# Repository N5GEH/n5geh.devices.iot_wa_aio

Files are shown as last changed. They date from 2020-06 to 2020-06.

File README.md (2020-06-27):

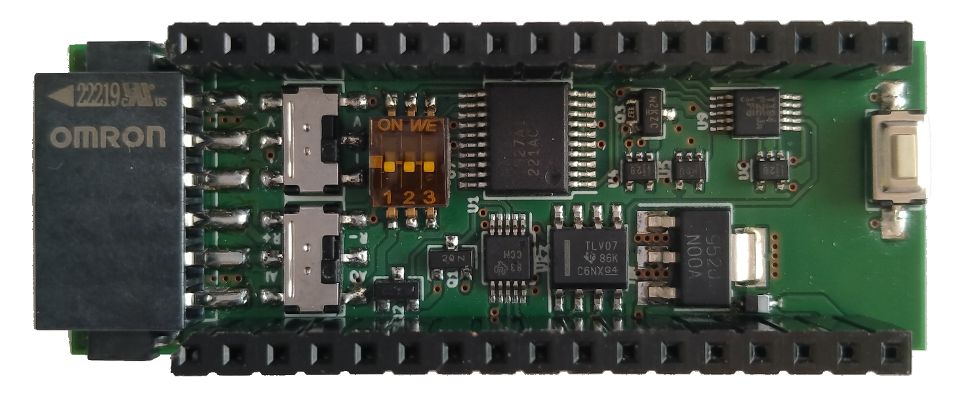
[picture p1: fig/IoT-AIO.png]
#   IoT-AIO <br/> Analog IO IoT Wireless Adapter

IoT-AIO is a wireless adapter for developing IoT applications for Industrial and Building Automation Systems based on the Espressif chipset ESP32. The adapter is compatible with:
- current loop signals (0/4-20 mA)
- voltage signals (0/2-10 V)
- passive sensors (RTD, Strain Gauge,..)

The library allows the implemention of IoT applications that rely on MQTT protocol via WiFi/NB-IoT/LTE Cat-M1 interfaces.

## Adapter versions
The Iot-AIO wireless adapter is available in two versions developed using [KiCAD 5.1](https://kicad-pcb.org/) and compatible with:
- [ESP32-PICO-KIT v4](https://docs.espressif.com/projects/esp-idf/en/latest/esp32/hw-reference/esp32/get-started-pico-kit.html) - is an ESP32-based mini development board produced by [Espressif](https://espressif.com/). The board features integrated Wifi and BLE capabilites.
- [FiPy](https://pycom.io/product/fipy/) - is an ESP32-based mini development board produced by [Pycom](https://pycom.io/). The board features integrated Wifi, BLE, LoRa, Sigfox, NB-IoT and LTE Cat-M1

## Development Framework
IoT-AIO relies on the Espressif IoT Development Framework [ESP-IDF](https://github.com/espressif/esp-idf), the official development framework for the [ESP32](https://espressif.com/en/products/hardware/esp32/overview) chip.

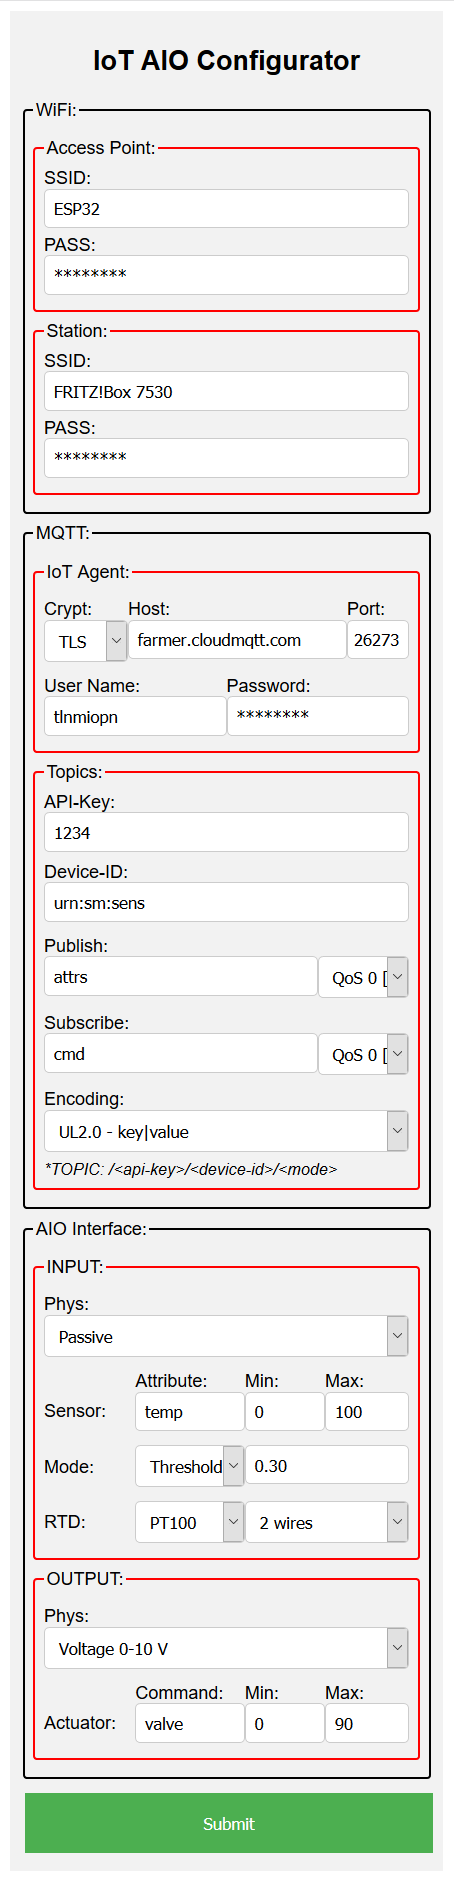
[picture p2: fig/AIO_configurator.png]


The adapter can be easily configured at run-time via a web interface based on HTML forms. The software configurator can be accessed by connecting to the adapter while in AP mode and typing in the browser the IP address `192.168.1.4`. After a succesful change in configuration the wireless adapter will reset. Source code and additional documentation can be found here:
- [AIO Configurator](Firmware/doc/aio_configurator.md)
- [HTML Request Page](Firmware/doc/aio_configurator_request.html)
- [HTML Response Page](Firmware/doc/aio_configurator_response.html)
- [Further Developments](Firmware/doc/developments.md)

## Configuration
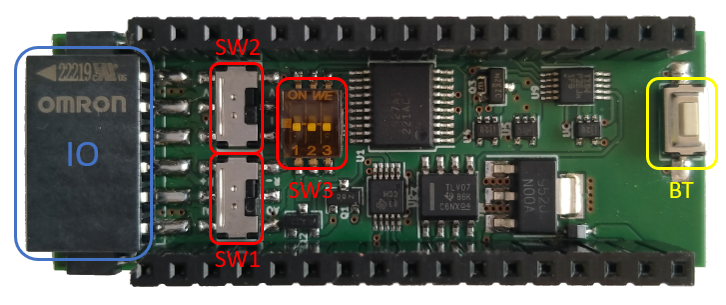
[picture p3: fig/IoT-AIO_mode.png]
IoT-AIO Mode


### Pinout
IO pinout (top-down):
- 0: GND
- 1: I- amperometric negative pin
- 2: I+ amperometric positive pin
- 3: AO/V- analog output/voltmetric negative pin
- 4: AI/V+ analog output/voltmetric positive pin
- 5: 12 V power supply (use input resistor 120 Ω / 1.5 W for 24 V input)

### Mode
The working mode of the adapter is selected using SW1
- UP: passive mode
    - pin 3 -> V-
    - pin 4 -> V+
- DOWN: analog IO mode
    - pin 3 -> AO
    - pin 4 -> AI

### Input mode
When SW1(DOWN) the input mode of the adapter is selected using SW2
- UP: voltage input mode allows for signals in the range 0 to 10 V
- DOWN: current input mode  allows for signals in the range 0 to 20 mA

### Output mode
When SW1(DOWN) the output mode of the adapter is selected using SW3(1):
- UP: voltage output mode allows for signals in the range 0 to 10 V
- DOWN: current output mode  allows for signals in the range 0 to 20 mA

### Passive mode
When SW1(UP) the output mode of the adapter is selected using SW3(2,3)

| Mode | SW3(2) | SW3(3) |
|:---:|:---:|:---:|
| 2-wires | UP | UP |
| 3-wires | UP |  DOWN  |
| 4-wires |  DOWN  |  DOWN  |

### Functions button
The push button BT performs multiple operations depending on the pressure time Tp.

| Pressure Time | Action |
|:---:|:---|
| Tp < 1s | Performs a soft-reset of the adapter |
|1s < Tp < 5s | Enables the AP mode. If not previously changed, the device will be visible by default with the SSID `ESP_<MAC>`, where <MAC> is the MAC address of the adapter network interface in hex format|
|5s < Tp | Performs a hard-reset of the adapter deleting the previously stored configuration|

# Publications

We kindly ask academic publications employing based or inspired to IoT-AIO to cite at least one of the following papers:

- M.H. Schraven, C. Guarnieri Calò Carducci, M.A. Baranski, D. Mueller, A. Monti, “Designing a Development Board for Research on IoT Appli-cations in Building Automation Systems,” 36th International Symposiumon  Automation  and  Robotics  in  Construction  (ISARC  2019),  Banff,Canada, 2019, pp. 82-90, [DOI: 10.22260/ISARC2019/0012](https://doi.org/10.22260/ISARC2019/0012)
- C. Guarnieri Calò Carducci, A. Monti, M. H. Schraven, M. Schumacher and D. Mueller, “Enabling ESP32-based IoT Applications in Building Automation Systems,” 2019 II Workshop on Metrology for Industry 4.0 and IoT (MetroInd4.0&IoT), Naples, Italy, 2019, pp. 306-311, [DOI: 10.1109/METROI4.2019.8792852](https://doi.org/10.1109/METROI4.2019.8792852)

# Copyright

2019-2020, Institute for Automation of Complex Power Systems, EONERC  

# License

<br />This work is licensed under a <a rel="license" href="http://creativecommons.org/licenses/by/4.0/">Creative Commons Attribution 4.0 International License</a>.

# Contact
EONERC ACS Logo (http://www.acs.eonerc.rwth-aachen.de)

- [Carlo Guarnieri Calò Carducci (PhD)](mailto:cguarnieri@eonerc.rwth-aachen.de)

[Institute for Automation of Complex Power Systems (ACS)](http://www.acs.eonerc.rwth-aachen.de)  
[EON Energy Research Center (EONERC)](http://www.eonerc.rwth-aachen.de)  
[RWTH University Aachen, Germany](http://www.rwth-aachen.de)

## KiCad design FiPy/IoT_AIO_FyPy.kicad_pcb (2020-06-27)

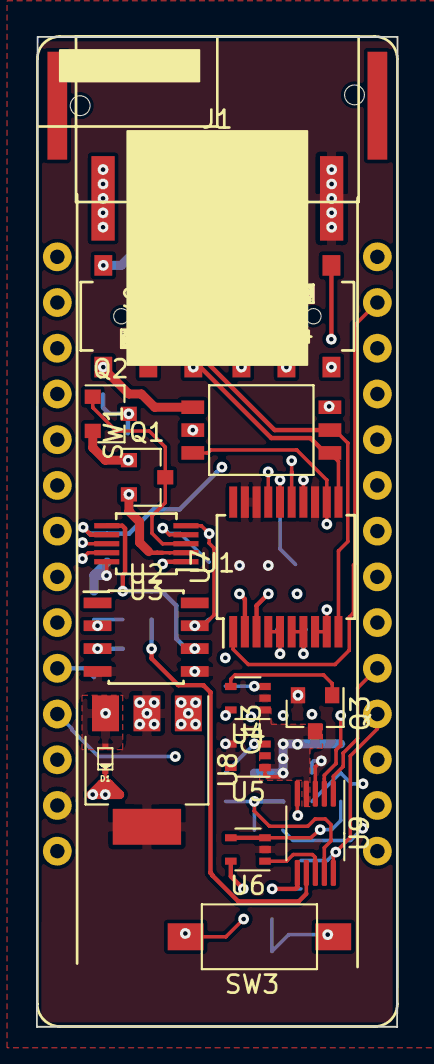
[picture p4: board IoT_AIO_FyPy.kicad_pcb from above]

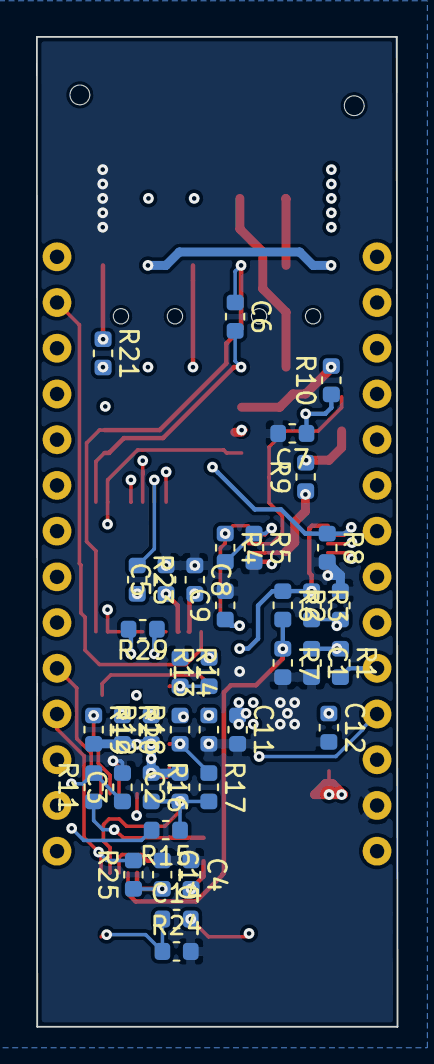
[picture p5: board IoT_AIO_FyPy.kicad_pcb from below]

Board: 4 copper layers, 20.0 x 55.0 mm, 57 parts (39 on the bottom side), 52 nets.

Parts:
C1, C3, C6: 1u; C_0603_1608Metric
C2, C4, C5, C8, C9, C10, C12, C13: 100n; C_0603_1608Metric
C7: 10n; C_0603_1608Metric
C11: 220n; C_0603_1608Metric
C14: 100n; R_0603_1608Metric
D1: D_Schottky; BAS52
J1: Conn_01x06; XW4L-06A1-H1
Q1: MMBT5087LT3G; SOT-23
Q2: ISS55EP06LMXTSA1; SOT-23
Q3: SI2302; SOT-23
R1, R11, R24, R25: 10k; R_0603_1608Metric
R2: 4.7k 0.1%; R_0603_1608Metric
R3: 10k 0.1%; R_0603_1608Metric
R4: 22k; R_0603_1608Metric
R5: 8.2k; R_0603_1608Metric
R6, R21: 33k 0.1%; R_0603_1608Metric
R7, R19: 3.3k 0.1%; R_0603_1608Metric
R8: 4990 0.1%; R_0603_1608Metric
R9, R10: 15; R_0603_1608Metric
R12, R14: 3.3k; R_0603_1608Metric
R13: 33k; R_0603_1608Metric
R15: 600 0.1%; R_0603_1608Metric
R16: 1k 0.1%; R_0603_1608Metric
R17: 2.2k 0.1%; R_0603_1608Metric
R18: 500; R_0603_1608Metric
R20: 45.3 0.1%; R_0603_1608Metric
R23: 4.7k; R_0603_1608Metric
R29: 400 0.1%; R_0603_1608Metric
SW1: SW_3PST; 416131160803
SW2: SW_SPDT_x2; AYZ0202AGRL
SW3: SW_Push; PTS636
SW4: SW_DPDT_x2; AYZ0202AGRL
U1: FiPy
U2: TLV07IDR; SOIC-8_3.9x4.9mm_P1.27mm
U3: XTR111AIDGQR; MSOP-10_3x3mm_P0.5mm
U4, U6: TLV333IDCKR; SOT-353_SC-70-5
U5: LM4040DCK-2.0; SOT-353_SC-70-5
U7: MAX31865; SSOP-20_5.3x7.2mm_P0.65mm
U8: LM340MP-5.0/NOPB; SOT-223-3_TabPin2
U9: TMUX1204; VSSOP-10_3x3mm_P0.5mm

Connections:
+3V3: C4.2, C5.1, C8.2, C10.2, C13.2, R12.2, R18.2, R23.2, R25.1, U1.26, U4.5, U6.5, U7.2, U7.3, U9.5, U9.6
+5V: D1.1, U1.28
+24V: C11.1, J1.6, U3.1, U8.1
/ADC_AI: C3.1, R11.2, U1.15
/AI: SW2.1, SW4.5
/AI/AOCAL: R6.2, R7.1, U9.7
/AI/Vcal: C2.1, R15.1, R16.2, R17.2, U9.9
/AO: R10.2, SW1.1, SW2.4
/AO/VREGF: C9.1, R4.1, U2.7, U3.5
/CAL_GPIO: R15.2, U1.10
/CS_SENSOR: R23.1, U1.6, U7.16
/DRDY_SENSOR: U1.13, U7.1
/IFORCE+: J1.3, SW1.3, U7.8, U7.9
/IFORCE-: J1.2, SW1.5, U7.12
/MISO_SENSOR: U1.11, U7.17
/MOSI_SENSOR: U1.12, U7.14
/MUX_A0: U1.5, U9.1
/MUX_A1: R25.2, U1.4, U9.10
/OFFSET_DAC: R13.2, U1.23
/RTDIN+: C6.1, SW1.4, SW2.3, U7.10
/RTDIN-: C6.2, SW1.6, SW2.6, U7.11
/SCK_SENSOR: U1.25, U7.15
/XTR111_EF: U1.18, U3.8
/XTR111_OD: U1.17, U3.9
/XTR111_PWM: R1.2, U1.24
GND: C1.2, C3.2, C4.1, C5.2, C7.2, C8.1, C9.2, C10.1, C11.2, C12.2, C13.1, J1.1, Q3.2, R2.2, R5.2, R7.2, R8.2, R14.1, R24.2, U1.27, U2.4, U3.10, U4.2, U6.2, U7.13, U7.18, U7.19, U8.2, U9.3
GNDA: C2.2, Q3.3, R12.1, R16.1, R19.2, R20.2, U4.1, U5.1, U9.4
unnamed: C1.1, R1.1, U2.3
unnamed: C7.1, Q2.3, R10.1
unnamed: C12.1, D1.2, U8.3
unnamed: C14.1, R24.1, SW3.1
unnamed: C14.2, SW3.2, U1.16
unnamed: J1.4, SW2.5
unnamed: J1.5, SW2.2
unnamed: Q1.1, Q2.2, R9.2
unnamed: Q1.2, R9.1, U3.2
unnamed: Q1.3, Q2.1, U3.3
unnamed: Q3.1, U4.4
unnamed: R2.1, R3.2, U2.2
unnamed: R3.1, R6.1, U2.6, U3.6
unnamed: R4.2, R5.1, U3.4
unnamed: R8.1, SW1.2, U3.7
unnamed: R11.1, U6.3, U6.4
unnamed: R13.1, R14.2, U4.3
unnamed: R17.1, R18.1, U5.3
unnamed: R19.1, SW4.2, U9.2
unnamed: R20.1, SW4.3, SW4.6
unnamed: R21.1, SW4.4
unnamed: R21.2, SW4.1
unnamed: R29.1, U7.4, U7.5
unnamed: R29.2, U7.6, U7.7
unnamed: U6.1, U9.8

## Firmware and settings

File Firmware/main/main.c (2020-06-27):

#include <stdio.h>
#include "esp_log.h"
#include "esp_system.h"

#include "AIO_Conf.h"
#include "AIO_Board.h"
#include "AIO_Netw.h"
#include "AIO_Mqtt.h"
#include "AIO_Intr.h"
#include "MAX31865.h"

static aio_conf_t aio_conf;
static const char *TAG = "APP";


void app_main(void)
{

	ESP_LOGI(TAG, "Startup..");
	ESP_LOGI(TAG, "Free memory: %d bytes", esp_get_free_heap_size());
	ESP_LOGI(TAG, "IDF version: %s", esp_get_idf_version());

	ESP_LOGI(TAG, "Configuring Log levels");
	esp_log_level_set("*", ESP_LOG_INFO);
	esp_log_level_set("MQTT_CLIENT", ESP_LOG_VERBOSE);
	esp_log_level_set("TRANSPORT_TCP", ESP_LOG_VERBOSE);
	esp_log_level_set("TRANSPORT_SSL", ESP_LOG_VERBOSE);
	esp_log_level_set("TRANSPORT", ESP_LOG_VERBOSE);
	esp_log_level_set("OUTBOX", ESP_LOG_VERBOSE);
	
	esp_log_level_set("MAX31865", ESP_LOG_WARN);
	esp_log_level_set("AIO_Board", ESP_LOG_INFO);
	esp_log_level_set("AIO_Conf", ESP_LOG_INFO);
	esp_log_level_set("AIO_Netw", ESP_LOG_INFO);
	esp_log_level_set("AIO_Mqtt", ESP_LOG_INFO);
	esp_log_level_set("AIO_Intr", ESP_LOG_INFO);


	ESP_LOGI(TAG, "Init modules..");
	init_CONF(&aio_conf, AIO_CONF_INIT_MEMORY);						// Init AIO Configuration
	init_AIO (&aio_conf);											// Init AIO Board
	init_NETW(&aio_conf);											// Init Network
	init_MQTT(&aio_conf);											// Init MQTT
	init_INTR();													// Init Interrupts

    while(1){
		vTaskDelay(100 / portTICK_PERIOD_MS);
        // vTaskDelay(portMAX_DELAY);
	}
}

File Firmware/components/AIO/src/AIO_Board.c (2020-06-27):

#include "AIO_Board.h"
#include <esp_log.h>

// ---------- Constants

#define RTD_REF			402.0
#define PWM_OFFS		0.00720000
#define PWM_GAIN		0.98930000
#define GPIO_ATTN		0.52621507	// GPIO * (R1//R3) / (R2 + R1//R3) = GPIO * (2k2//1k) / (619 + 2k2//1k) = GPIO * GPIO_ATTN
#define VREF_ATTN		0.31250000	// VREF_EXT * 1.0 / (1.0 + 2.2) = VREF_EXT * VREF_ATTN
#define AI_V_ATTN		0.09140969	// Vi = ADC / 2^12 * VREF / (3.32 / (3.32 + 33)) = ADC / 2^12 * VREF / AI_V_ATTN
#define AI_I_ATTN		44.6865752	// Ii = ADC / 2^12 * VREF / (45.3//3300)         = ADC / 2^12 * VREF / AI_I_ATTN
#define AO_V_GAIN		3.15517241	// VOUT = VDAC * (1 + 10 / 4.64) = VDAC * AO_V_GAIN

// ---------- PWM

#define PWM_HS_TIMER	LEDC_TIMER_0
#define PWM_HS_MODE		LEDC_HIGH_SPEED_MODE
#define PWM_HS_CH0_GPIO	PIN_XTR_DAC
#define PWM_HS_CH0_CHAN	LEDC_CHANNEL_0


static const char *TAG = "AIO_Board";

static aio_dev_t AIO;

// ---------- ADC Buffer
// static uint8_t	x[256];
// static float	y[256];
bool autocalibration;

// ---------- PWM descriptors
static ledc_timer_config_t	 pwm_timer;
static ledc_channel_config_t pwm_channel;

// ------------------------------------------------------
//			Configuration Section
// ------------------------------------------------------

void set_MUX(mux_state_t val)
{
	switch (val) {

	case MUX_OFF:
		ESP_LOGI(TAG, "MUX OFF");
		gpio_set_level((gpio_num_t)PIN_MUX_EN, 0);
		gpio_set_level((gpio_num_t)PIN_MUX_A0, 0);
		gpio_set_level((gpio_num_t)PIN_MUX_A1, 0);
		break;

	case MUX_ON:
		ESP_LOGI(TAG, "MUX ON");
		gpio_set_level((gpio_num_t)PIN_MUX_EN, 1);
		gpio_set_level((gpio_num_t)PIN_MUX_A0, 0);
		gpio_set_level((gpio_num_t)PIN_MUX_A1, 0);
		break;

	case MUX_VIN:
		ESP_LOGI(TAG, "MUX VIN");
		gpio_set_level((gpio_num_t)PIN_MUX_A0, 0);
		gpio_set_level((gpio_num_t)PIN_MUX_A1, 0);
		break;

	case MUX_CAL:
		ESP_LOGI(TAG, "MUX CAL");
		gpio_set_level((gpio_num_t)PIN_MUX_A0, 1);
		gpio_set_level((gpio_num_t)PIN_MUX_A1, 0);
		break;

	case MUX_AGND:
		ESP_LOGI(TAG, "MUX AGND");
		gpio_set_level((gpio_num_t)PIN_MUX_A0, 0);
		gpio_set_level((gpio_num_t)PIN_MUX_A1, 1);
		break;

	case MUX_VOUT:
		ESP_LOGI(TAG, "MUX VOUT");
		gpio_set_level((gpio_num_t)PIN_MUX_A0, 1);
		gpio_set_level((gpio_num_t)PIN_MUX_A1, 1);
		break;

	default:
		break;
	}
	vTaskDelay(500 / portTICK_PERIOD_MS);		// 5 Time Constants
}

float map_raw(float x, float _in_min, float _in_max, float _out_min, float _out_max)
{
	float m = (_out_max - _out_min) / (_in_max - _in_min);
	float y = (m * (x - _in_min) + _out_min);
	return y;
}

float map(float x, aio_conv_t _type)
{
	switch (_type)
	{
	case AI_CODE_TO_VOLT:
		return (AIO.VREF_ADC * x / AIO.AI_code_max);		// V = VREF * CODE / 2^12, V = [0,VREF]
		break;

	case AI_VOLT_TO_PHYS:
		if ((AIO.AO == AIO_VOLTAGE_0_10) || (AIO.AO == AIO_VOLTAGE_2_10))
			return map_raw(x, 0, AIO.VREF_ADC, 0.0, AIO.VREF_ADC / AI_V_ATTN);
		if ((AIO.AO == AIO_CURRENT_0_20) || (AIO.AO == AIO_CURRENT_4_20))
			return map_raw(x, 0, AIO.VREF_ADC, 0.0, AIO.VREF_ADC / AI_I_ATTN * 1000.0);
		break;

	case AI_PHYS_TO_UNIT:
		return map_raw(x, AIO.AI_phys_min, AIO.AI_phys_max, AIO.AI_unit_min, AIO.AI_unit_max);
		break;

	case AO_UNIT_TO_PHYS:
		return map_raw(x, AIO.AO_unit_min, AIO.AO_unit_max, AIO.AO_phys_min, AIO.AO_phys_max);
		break;

	case AO_PHYS_TO_VOLT:
		if ((AIO.AO == AIO_VOLTAGE_0_10) || (AIO.AO == AIO_CURRENT_0_20))
			return map_raw(x, AIO.AO_phys_min, AIO.AO_phys_max, 0.0 / AO_V_GAIN, 10.0 / AO_V_GAIN);
		if ((AIO.AO == AIO_VOLTAGE_2_10) || (AIO.AO == AIO_CURRENT_4_20))
			return map_raw(x, AIO.AO_phys_min, AIO.AO_phys_max, 2.0 / AO_V_GAIN, 10.0 / AO_V_GAIN);
		break;

	case AO_VOLT_TO_CODE:
		return (x - PWM_OFFS) * AIO.AO_code_max / AIO.VSUP / PWM_GAIN;		// V = CODE / 2^9 * VSUP * PWMG + PWMO, V = [0,VSUP]
		break;

	default:
		break;
	}

	return 0;
}

void set_raw_channel(uint8_t ch)
{
	pwm_channel.gpio_num = ch;
	ledc_channel_config(&pwm_channel);
}

void set_raw(uint16_t code)
{
	ledc_set_duty(pwm_channel.speed_mode, pwm_channel.channel, code & 0x01FF);
	ledc_update_duty(pwm_channel.speed_mode, pwm_channel.channel);
}

float get_raw(uint16_t n)
{
	double sum = 0;

	for (int i = 0; i < n; i++) {
		if (AIO.AI == AIO_PASSIVE)
			if(!autocalibration) {
				sum += max31865_temperature();
				continue;
			}
		
		sum += adc1_get_raw((adc1_channel_t)ADC_CHANNEL_1);
	}
	float _code = sum / ((float)n);

	return _code;
}

void AIO_set(float _unit)
{
	if (AIO.AO == AIO_DISABLED)
		return;

	if (_unit > AIO.AO_unit_max)
		_unit = AIO.AO_unit_max;
	if (_unit < AIO.AO_unit_min)
		_unit = AIO.AO_unit_min;

	float _phys = map(_unit, AO_UNIT_TO_PHYS);
	float _volt = map(_phys, AO_PHYS_TO_VOLT);
	float _code = map(_volt, AO_VOLT_TO_CODE);

	set_raw(_code);
}
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

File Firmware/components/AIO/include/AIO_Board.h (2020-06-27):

#ifndef _AIO_BOARD_H_
#define _AIO_BOARD_H_

#include "freertos/FreeRTOS.h"
#include "freertos/task.h"
#include "freertos/queue.h"
#include "driver/adc.h"
#include "driver/dac.h"
#include "driver/ledc.h"
#include "driver/gpio.h"
#include "MAX31865.h"
#include "AIO_Conf.h"


// ---------- GPIO Definitions
#define PIN_RESET		 0

#define PIN_ADC			37	// ADC1_CH1
#define PIN_DAC			DAC_CHANNEL_2	// 26
#define PIN_CAL			 4

#define PIN_XTR_OD		12	// Output Disable
#define PIN_XTR_EF		14	// Output Failure
#define PIN_XTR_DAC		15	// Output PWM

#define PIN_MAX_CS		 5	// VSPICS0	SPI Chips Select
#define PIN_MAX_RDY		 9	//			SPI Data Ready
#define PIN_MAX_SCK		18	// VSPICLK	SPI Clock
#define PIN_MAX_MISO	19	// VSPIQ	SPI MISO
#define PIN_MAX_MOSI	23	// VSPID	SPI Chips Select

#define PIN_MUX_EN		22	// MUX Enable
#define PIN_MUX_A0		10	// MUX Select line 0
#define PIN_MUX_A1		21	// MUX Select line 1

// ---------- MUX

typedef enum {
	MUX_OFF = 0,
	MUX_ON,
	MUX_VIN,
	MUX_CAL,
	MUX_AGND,
	MUX_VOUT
} mux_state_t;

// ---------- AIO Modes

typedef enum {
	AIO_DISABLED = 0,
	AIO_VOLTAGE_0_10,
	AIO_VOLTAGE_2_10,
	AIO_CURRENT_0_20,
	AIO_CURRENT_4_20,
	AIO_PASSIVE
} aio_mode_t;

typedef enum {
	AI_CODE_TO_VOLT = 0,
	AI_VOLT_TO_PHYS,
	AI_PHYS_TO_UNIT,
	AO_UNIT_TO_PHYS,
	AO_PHYS_TO_VOLT,
	AO_VOLT_TO_CODE
} aio_conv_t;

typedef struct {
	aio_mode_t AI;
	aio_mode_t AO;

	float	AI_unit_max;
	float	AI_unit_min;
	float	AO_unit_max;
	float	AO_unit_min;

	float	AI_phys_max;
	float	AI_phys_min;
	float	AO_phys_max;
	float	AO_phys_min;

	float	AI_code_max;
	float	AI_code_min;
	float	AO_code_max;
	float	AO_code_min;

	uint8_t	OFFS_CAL;
	float	OFFS_ADC;
	float	VREF_EXT;
	float	VREF_ADC;
	float	VSUP;
	float	VSUP1;
} aio_dev_t;

#ifdef __cplusplus
extern "C" {
#endif

esp_err_t init_AIO(aio_conf_t *aio_conf);

void  AIO_autocalibration();
void  AIO_set(float _unit);
float AIO_get(uint16_t n);

#ifdef __cplusplus
}
#endif //__cplusplus

#endif
